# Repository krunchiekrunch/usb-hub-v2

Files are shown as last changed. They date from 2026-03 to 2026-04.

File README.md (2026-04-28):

# usb-hub-v2

# About

This is a 4 port USB 2.0 hub, it has a reverse voltage protection circuit in case the devices sends too much voltage and also has decoupling capacitors to protect the host USB ports. There are both USB-A and a USB-C port (which Supports USB-C PD at 5V) that can be connected to a PC, although only one connector should be used to connect for data at a time, but the other one can be used to supply higher power to the devices.

# Why I made it

Previously, I made [usb-hub version 1](https://github.com/krunchiekrunch/usb-hub), but unfortunately, there were many flaws which made it so that it's incompatilable with many of my devices such as
- poorly placed decoupling capacitors
- a reverse voltage diode with a massive voltage drop
- the lack of a external crystal

 So I created version 2 which aims to solve those issues with the addition of
- a ground plane
- an external crystal
- differential traces for better signal integritiy
- P-Channel MOSFET for reverse voltage protection (Less voltage drop)
- SMD components for easier assembly
- a more secure case design. 

[OnShape Document](https://cad.onshape.com/documents/efce2298bdb4cf98a9c696d8/w/922ae4eee0c64909c767a4ca/e/18ffe383e3b3a38790e4ceb5)

As seen in the SL2.1A datasheet's reference circuit and many online designs, loading capacitors for the crystal is not required for this IC.



# Assembly instructions

Solder all the SMD components first, then the USB ports, insert and secure the heatset inserts in the 2 holes on the bottom of the case, then use 2x M3 screws (max 5.5mm) to screw in and secure the PCB, then align the friction lock poles and push the top of the case in.

# Images

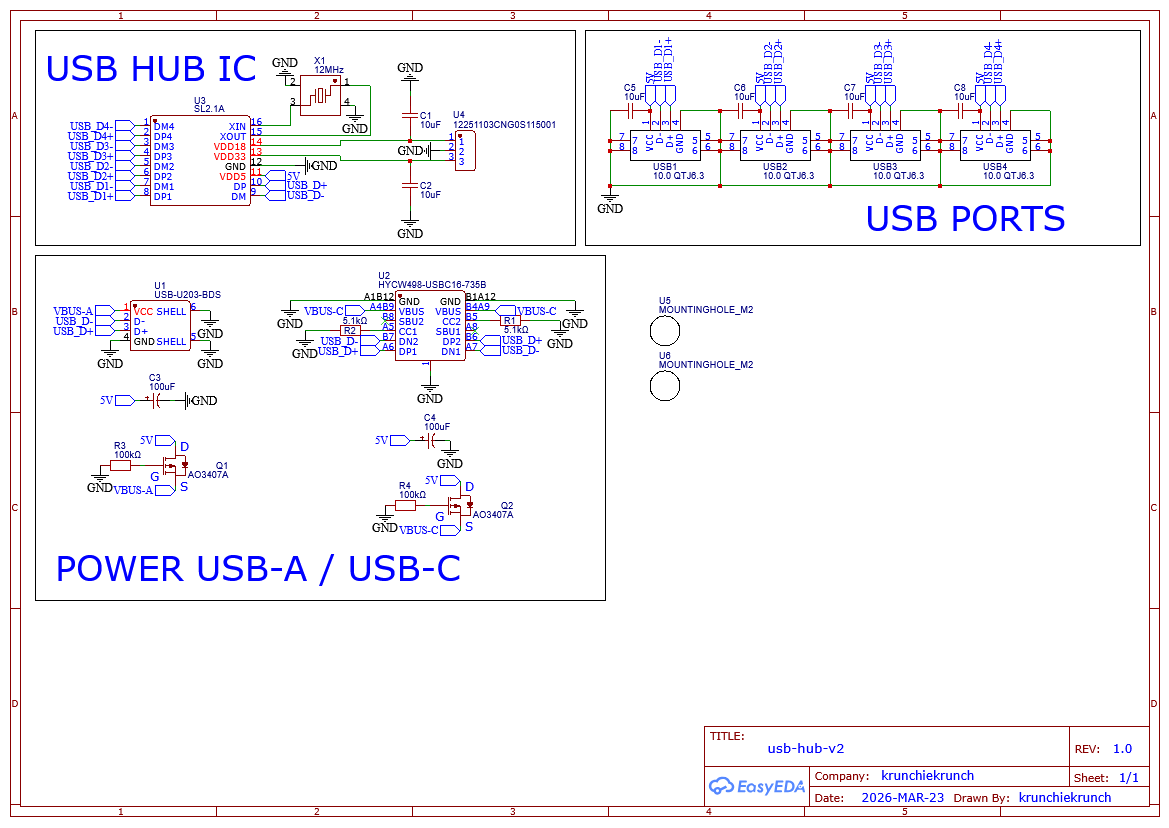
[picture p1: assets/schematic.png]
Schematic


| PCB | 3D Preview | Case |
|-----|---|---|
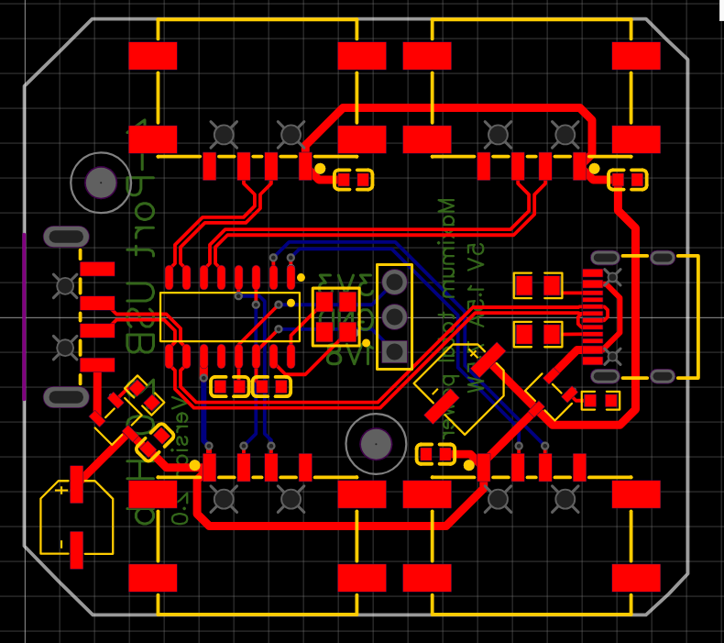
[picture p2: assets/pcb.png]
PCB
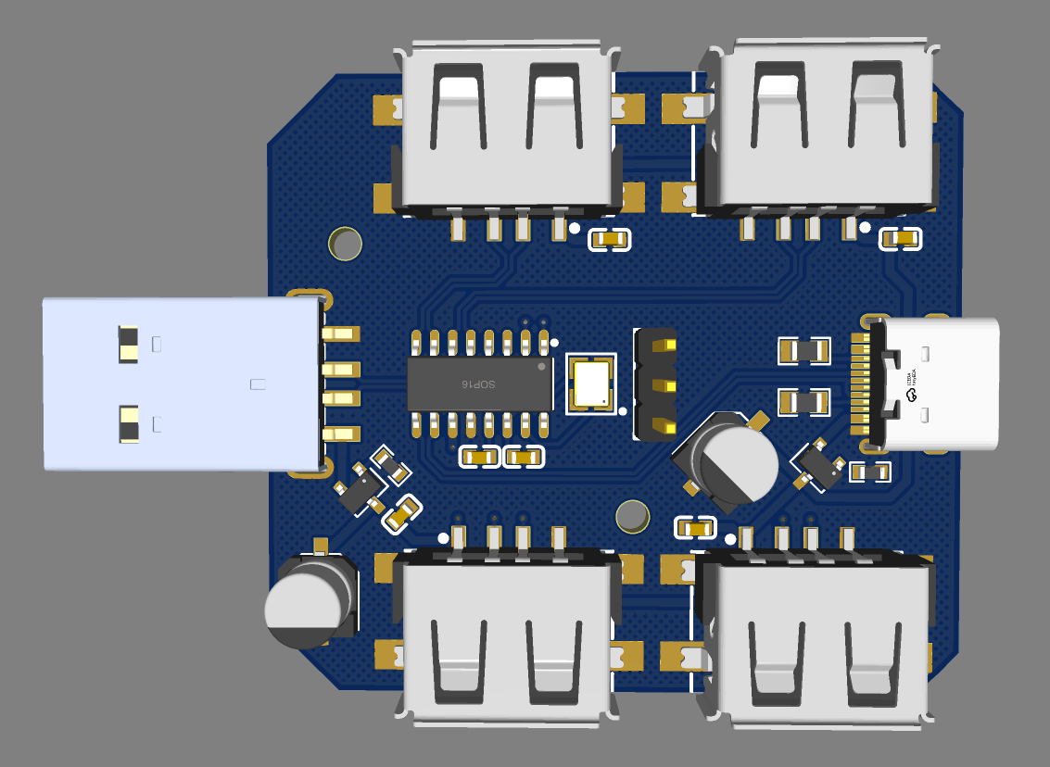
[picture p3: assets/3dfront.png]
3D-Front
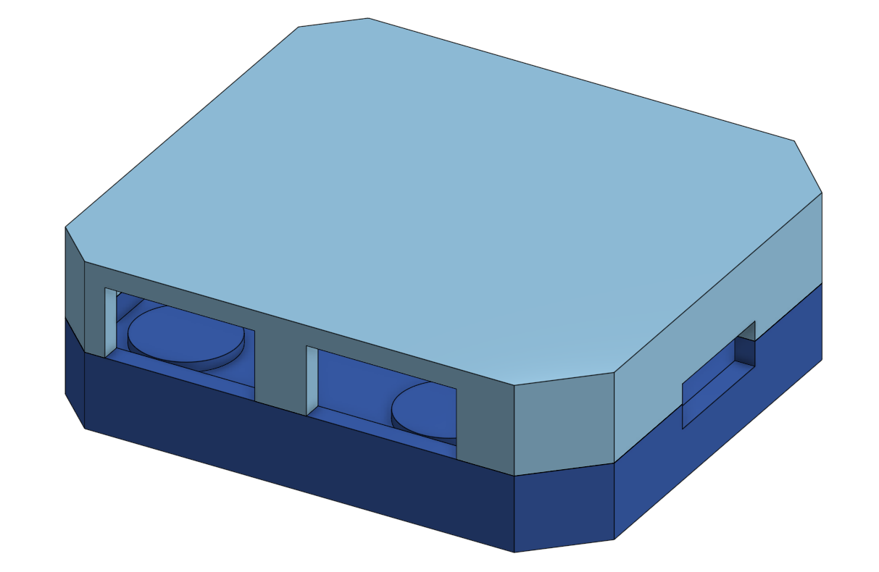
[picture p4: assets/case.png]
Case1
|  |  |  |
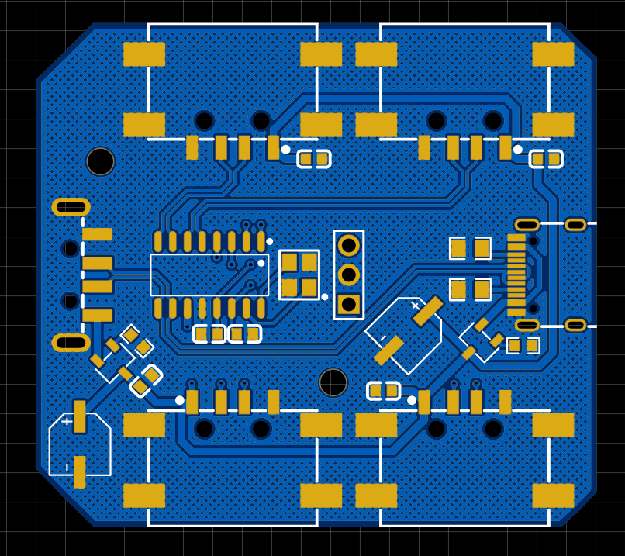
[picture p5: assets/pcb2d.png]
PCB-2D
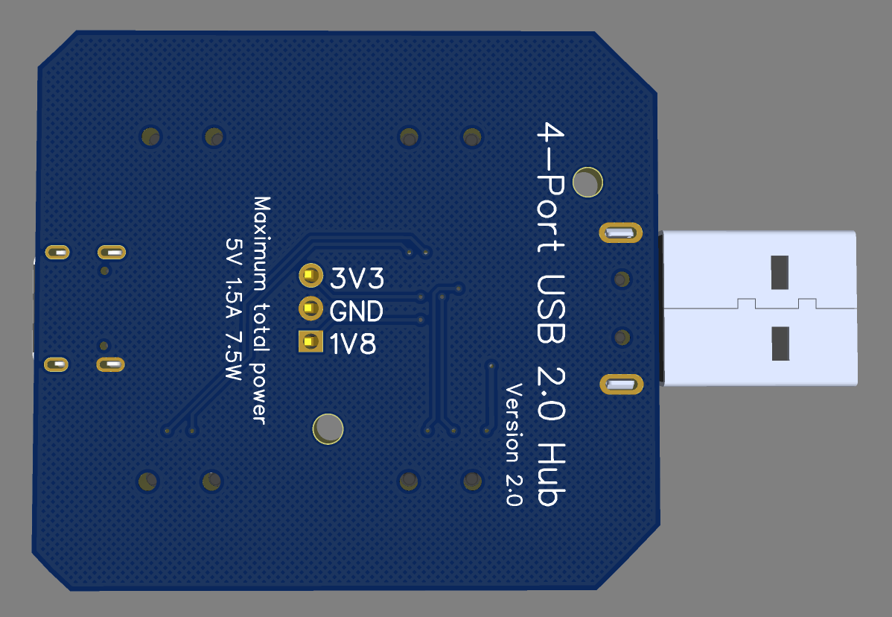
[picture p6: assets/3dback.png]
3D-Back
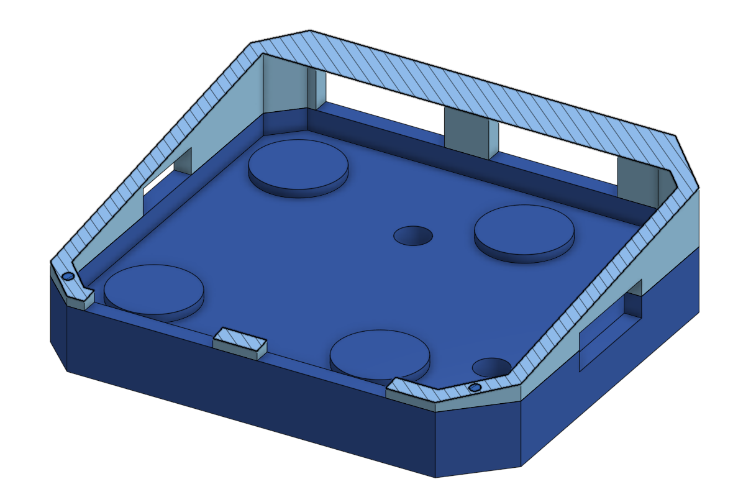
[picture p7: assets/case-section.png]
Case2
|  |  |  |

# BOM

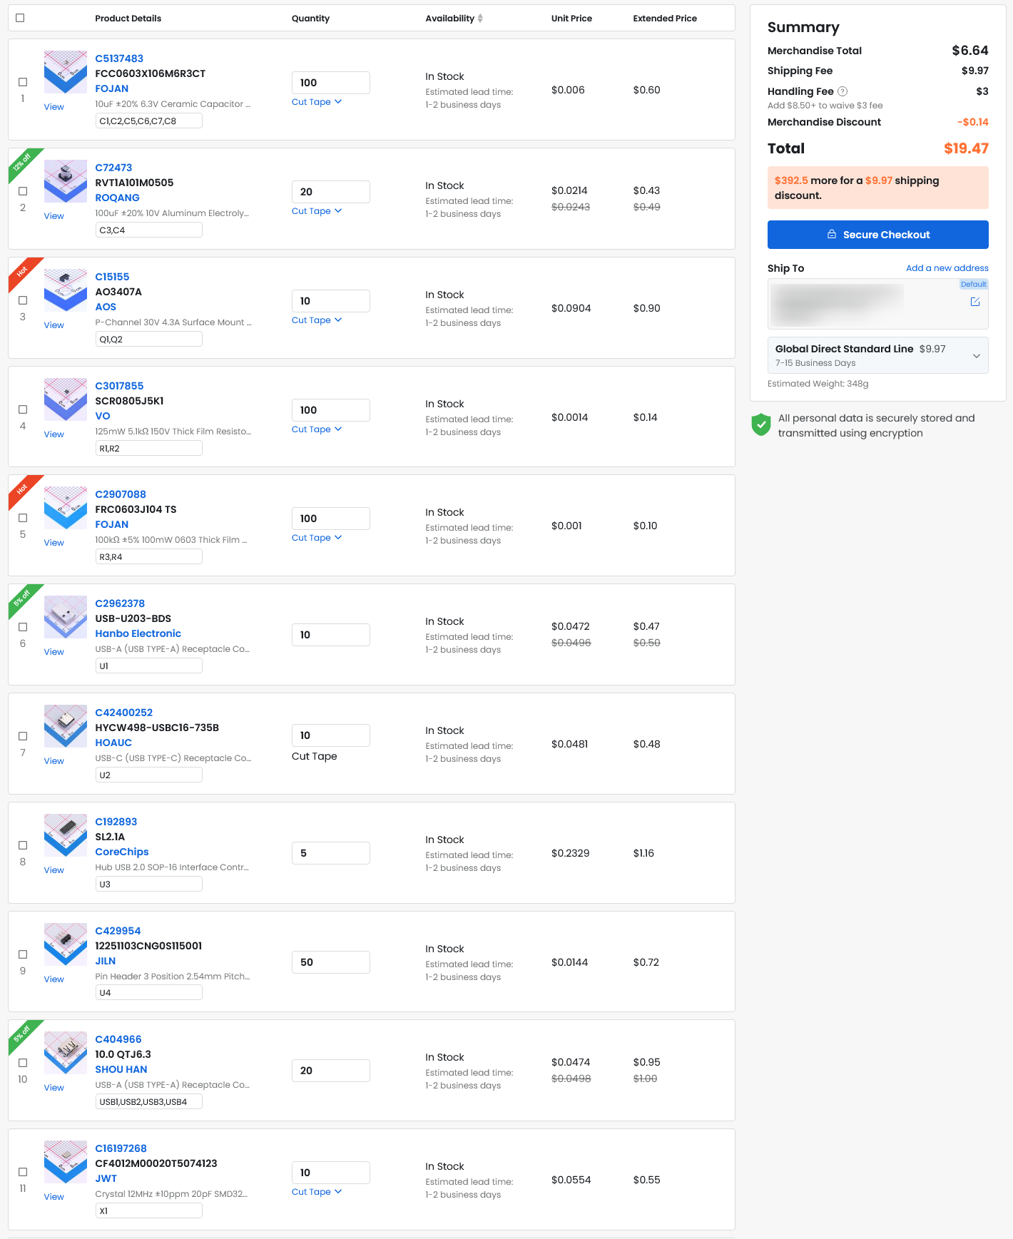
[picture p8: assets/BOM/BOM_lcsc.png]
LCSC Cart


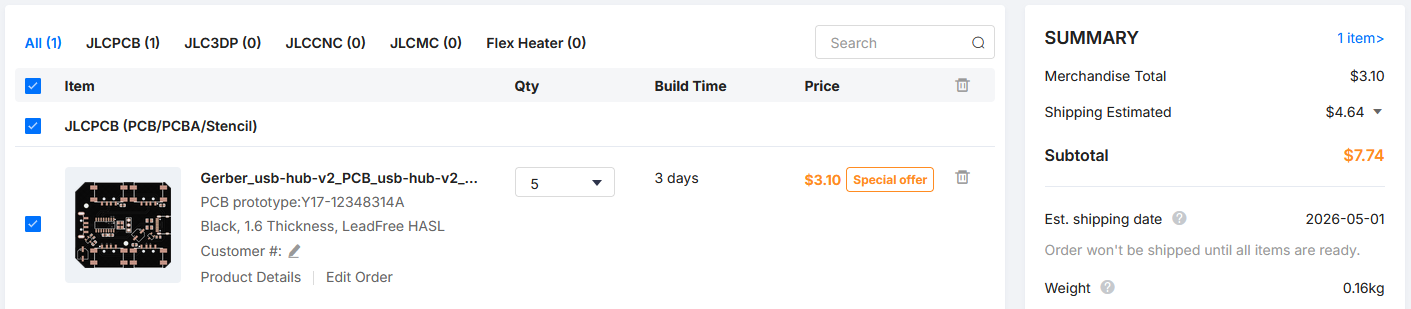
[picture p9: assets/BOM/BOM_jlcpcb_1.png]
JLCPCB Cart


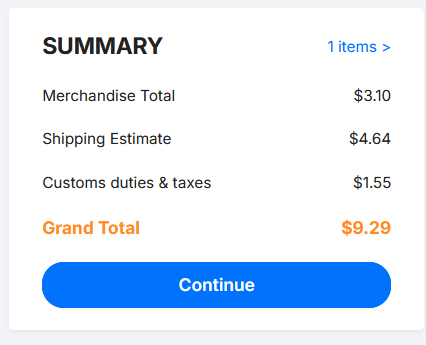
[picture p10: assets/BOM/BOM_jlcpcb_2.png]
JLCPCB Cart


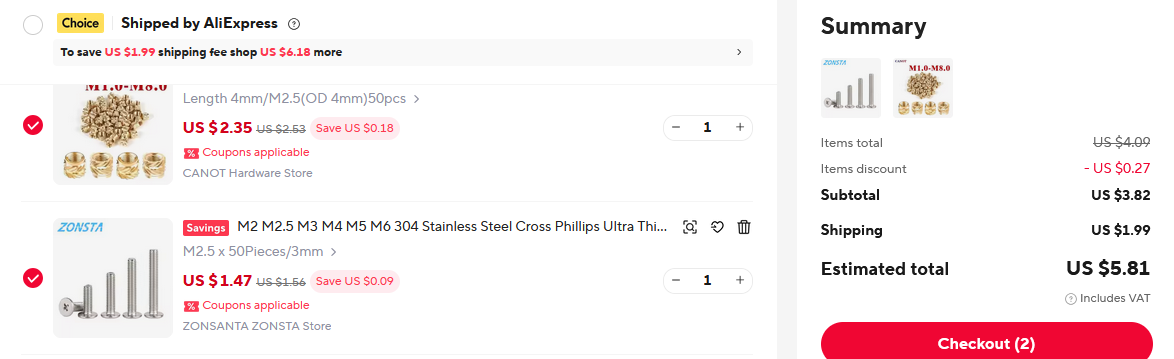
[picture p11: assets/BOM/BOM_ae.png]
AE Cart


| LCSC# | Customer # | Quantity | Extended Price($) | Product Link |
| --- | --- | --- | --- | --- |
| C5137483  | C1,C2,C5,C6,C7,C8 | 100 | 0.6 | [https://www.lcsc.com/product-detail/C5137483.html](https://www.lcsc.com/product-detail/C5137483.html) |
| C72473 | C3,C4 | 20 | 0.43 | [https://www.lcsc.com/product-detail/C72473.html](https://www.lcsc.com/product-detail/C72473.html) |
| C15155 | Q1,Q2 | 10 | 0.9 | [https://www.lcsc.com/product-detail/C15155.html](https://www.lcsc.com/product-detail/C15155.html) |
| C3017855  | R1,R2 | 100 | 0.14 | [https://www.lcsc.com/product-detail/C3017855.html](https://www.lcsc.com/product-detail/C3017855.html) |
| C2907088  | R3,R4 | 100 | 0.1 | [https://www.lcsc.com/product-detail/C2907088.html](https://www.lcsc.com/product-detail/C2907088.html) |
| C2962378  | U1 | 10 | 0.47 | [https://www.lcsc.com/product-detail/C2962378.html](https://www.lcsc.com/product-detail/C2962378.html) |
| C42400252 | U2 | 10 | 0.48 | [https://www.lcsc.com/product-detail/C42400252.html](https://www.lcsc.com/product-detail/C42400252.html) |
| C192893 | U3 | 5 | 1.16 | [https://www.lcsc.com/product-detail/C192893.html](https://www.lcsc.com/product-detail/C192893.html) |
| C429954 | U4 | 50 | 0.72 | [https://www.lcsc.com/product-detail/C429954.html](https://www.lcsc.com/product-detail/C429954.html) |
| C404966 | USB1,USB2,USB3,USB4 | 20 | 0.95 | [https://www.lcsc.com/product-detail/C404966.html](https://www.lcsc.com/product-detail/C404966.html) |
| C16197268 | X1 | 10 | 0.55 | [https://www.lcsc.com/product-detail/C16197268.html](https://www.lcsc.com/product-detail/C16197268.html) |
| | Heatset inserts (M2.5x4mm) | 2 | 2.35 | [https://www.aliexpress.com/item/1005007640664497.html](https://www.aliexpress.com/item/1005007640664497.html) |
| | Screws (M2.5x3mm) | 2 | 1.47 | [https://www.aliexpress.com/item/1005003670389142.html](https://www.aliexpress.com/item/1005003670389142.html) |
| | AliExpress Shipping | | 1.99 | |
| | LCSC Fees (Handling+Shipping) | | 12.97 | |
| | PCB (Incl. shipping+VAT) | 5 | 9.29 | [https://jlcpcb.com](https://jlcpcb.com) |
| Total | | | 34.57 | |

blueprint_logo_centered

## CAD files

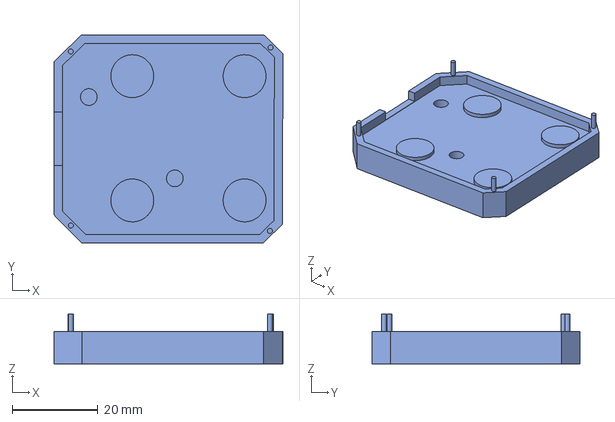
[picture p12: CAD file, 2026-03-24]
case-cad/casebottom.step
53.4 x 48.5 x 11.6 mm

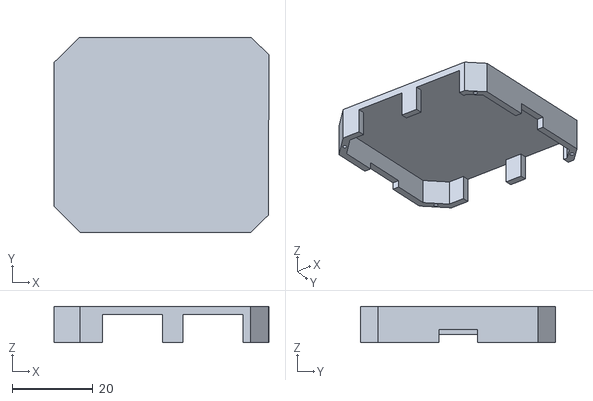
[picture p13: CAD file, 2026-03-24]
production/casetop.stl
53.4 x 48.5 x 9.00

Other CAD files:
case-cad/casetop.step
production/casebottom.stl

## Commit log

2026-02-13 files and readme
    [case-bottom.step, case-bottom.stl, case-top.step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]
2026-02-13 updated pcb design, panelized pcb
    [BOM_usb-hub-v2_2026-02-13.csv, PickAndPlace_PCB_usb-hub-v2_2_2026-02-13.csv]
2026-02-14 updated bom
    [BOM.csv]
2026-02-14 added urls to bom
    [BOM.csv]
2026-02-14 README bom table
2026-03-24 updated case design, pcb crystal
    [BOM.csv, BOM_usb-hub-v2_2026-02-13.csv, BOM_usb-hub-v2_2026-03-23.csv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]
2026-04-01 Enhance README with detailed USB hub v2 information
    Updated the README with improved descriptions and assembly instructions for the USB hub v2, including details on design improvements and component specifications.
2026-04-11 updated pcb silkscreen design, added panelized gerber
2026-04-28 Updated PCB layout, uploaded coresponding files, updated BOM to reflect current prices
    [BOM_usb-hub-v2_2026-03-23.csv, BOM_usb-hub-v2_2026-04-28.csv, PickAndPlace_PCB_usb-hub-v2_2_2026-03-23.csv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]
2026-04-28 updated BOM file and README table, updated images
    [BOM.csv]
